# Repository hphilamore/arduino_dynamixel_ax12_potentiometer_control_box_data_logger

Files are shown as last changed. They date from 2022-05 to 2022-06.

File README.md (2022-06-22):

A robot tentacle actuated uisng 3 dynamixel ax-12 servo motors. Circuit based on an arduino uno and DFrobot Smart Arduino Digital Servo Shield for Dynamixel AX.

__________________________________________________________________________________________

Robot Tentacle Control Instructions 

1.	Turn on by connecting to mains power
2.	The motors will take approx. 10 seconds to initialise - once this setup is completed, the green LEDs on the sliders will come on. 
(If during this time the green LEDs flash 5 times, the SD card is not connected/setup correctly and logging will not take place. Fix the problem then press the reset button on the Arduino to restart.)
3.	Control the robot tentacle by moving the sliders
4.	To record the motor angles during operation, press the blue button. The light on the button will come on to indicate logging has started.
(If no light comes on, there is a problem with the SD card.) 
5.	To stop recording press the blue button again. 
It is important to stop any recordings before powering off the system to avoid corrupting the SD card and losing data!

__________________________________________________________________________________________

Bill of Materials 

- Laser cut parts (.dxf file in repo)
- 1 x Arduino Uno: https://uk.rs-online.com/web/p/arduino/7154081/
- 1 x SD card module + SD card: https://www.amazon.co.uk/arduino-sd-card-module/s?k=arduino+sd+card+module
- 1 x RTC module: hhttps://learn.sparkfun.com/tutorials/real-time-clock-module-hookup-guide/all
- 3 x Slider potentiometer with LED: https://uk.rs-online.com/web/p/potentiometers/7703135/
- 3 x Latching switch with LED : https://uk.rs-online.com/web/p/push-button-switches/8207555/
- 3 x 330 ohm resistor
- power supply (7-12V): https://www.amazon.co.uk/gp/product/B09DGCJFRC/ref=ppx_yo_dt_b_asin_title_o01_s00?ie=UTF8&psc=1
- Arduino Screw Terminal Hat : https://www.amazon.co.uk/gp/product/B097G95T7Y/ref=ppx_yo_dt_b_asin_title_o05_s00?ie=UTF8&psc=1
- DFrobot Smart Arduino Digital Servo Shield for Dynamixel AX : https://www.dfrobot.com/product-958.html
- stand-offs
- strip-board

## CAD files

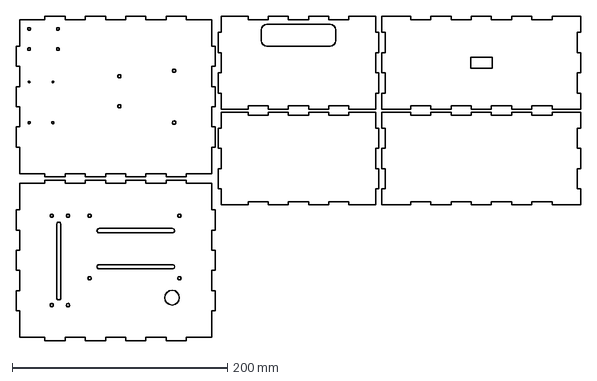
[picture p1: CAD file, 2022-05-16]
case.dxf
524.0 x 301.0 mm

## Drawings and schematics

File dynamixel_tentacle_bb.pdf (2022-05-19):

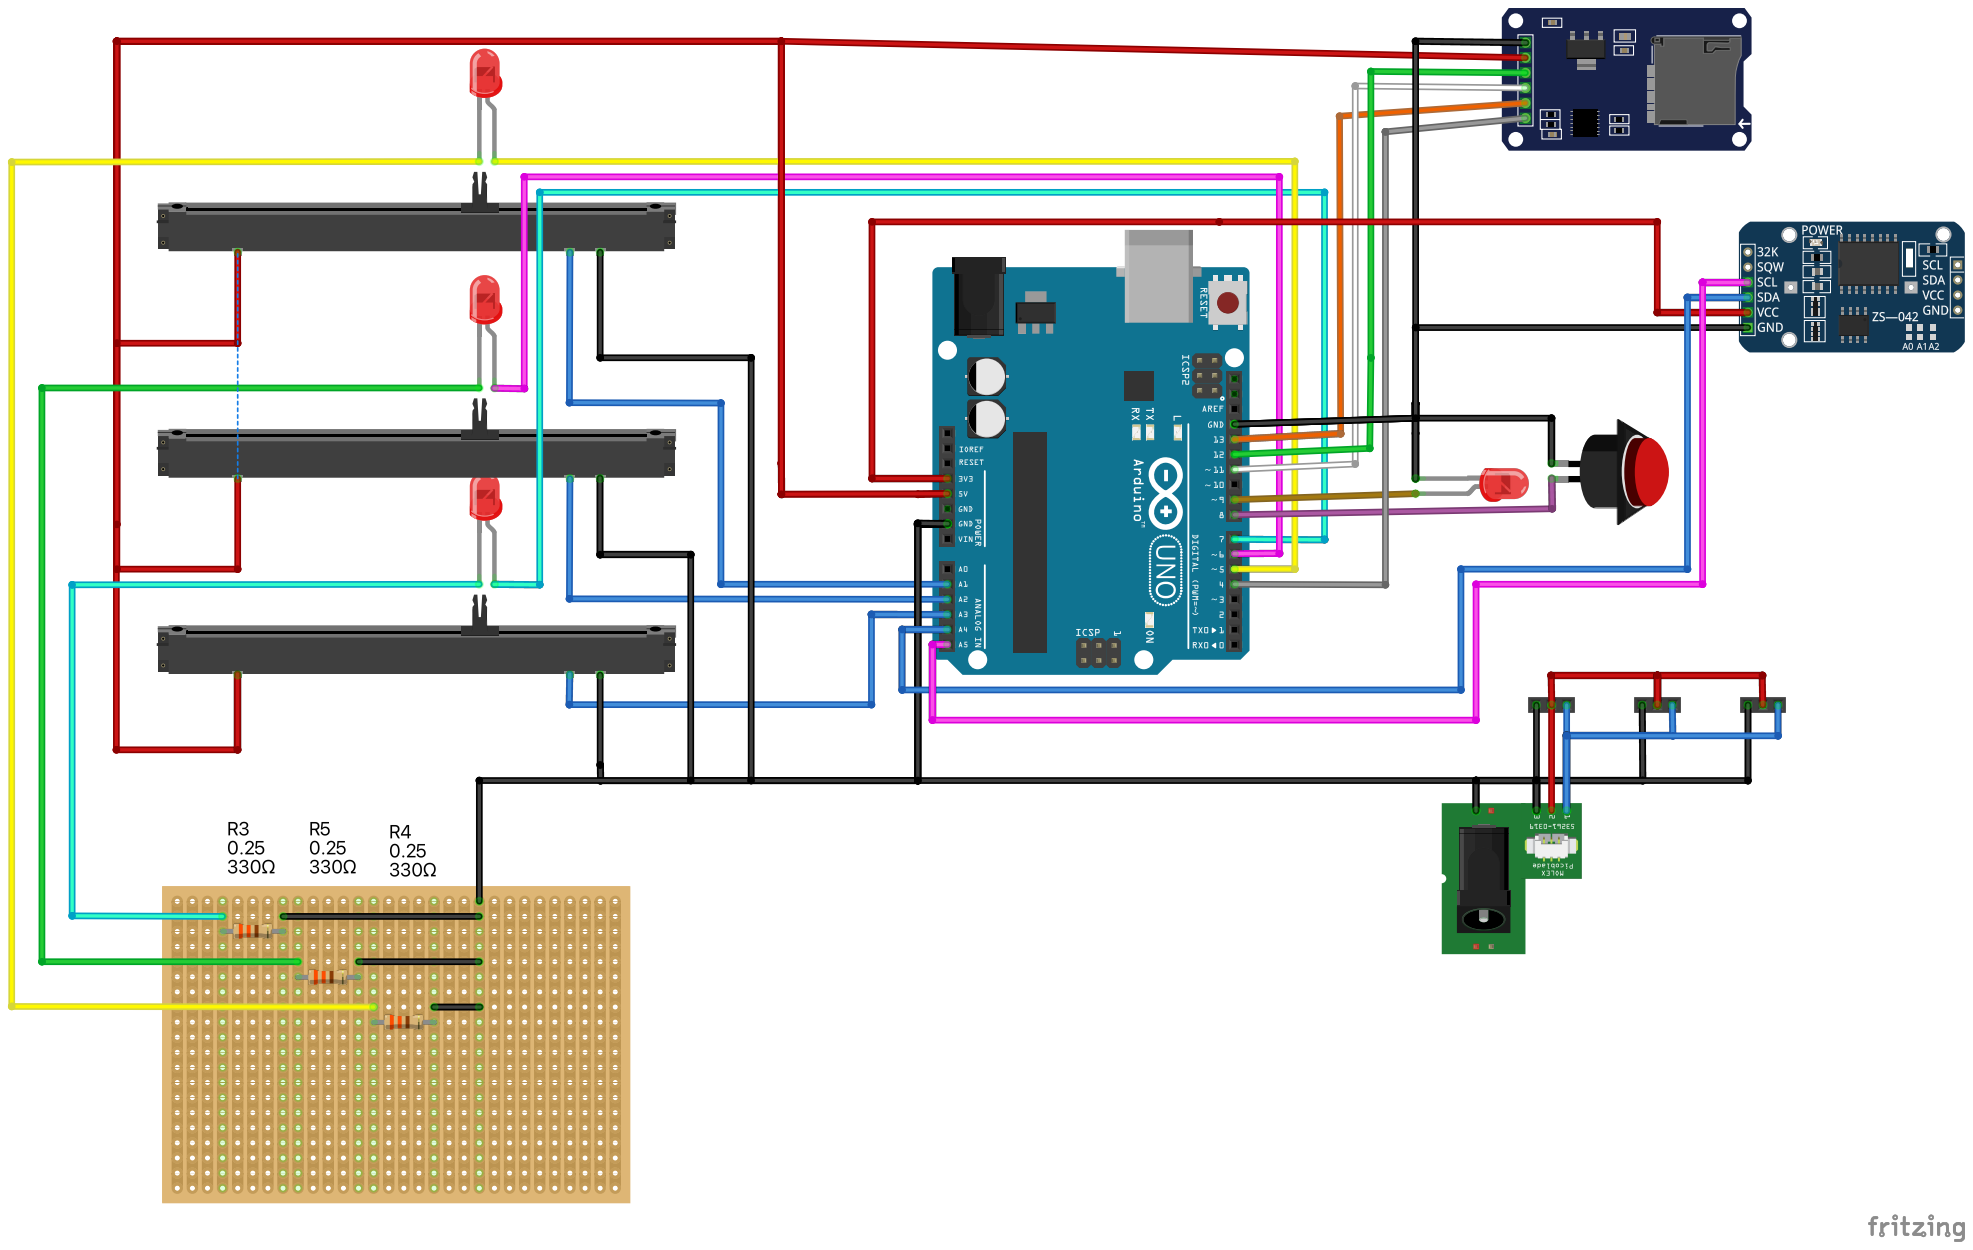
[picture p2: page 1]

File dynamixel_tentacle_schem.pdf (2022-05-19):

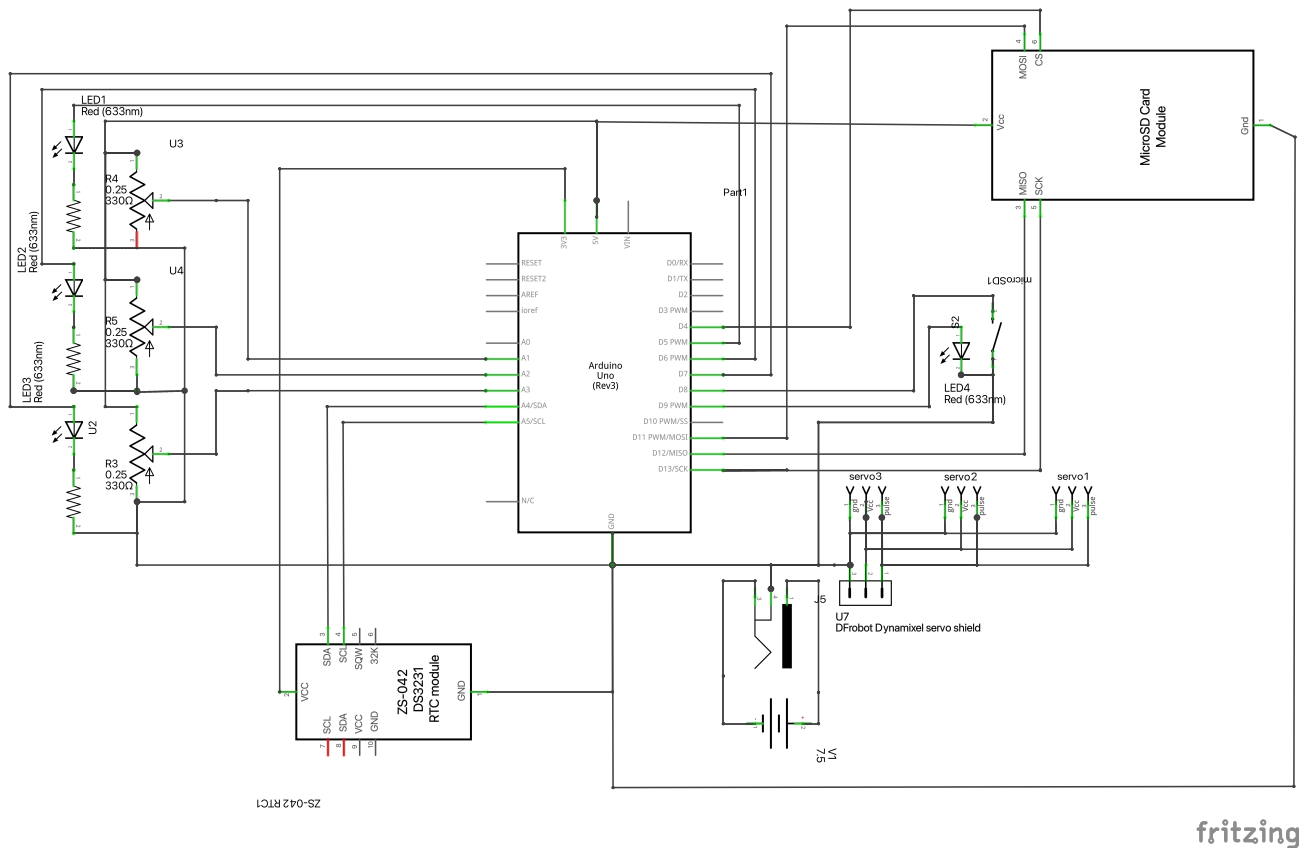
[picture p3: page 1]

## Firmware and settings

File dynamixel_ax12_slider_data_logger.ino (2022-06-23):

/*
 * 
Potentiometer sliders to control the position of 3 Dynamixel A-12 
digital servo motors Latching push button is used to control 
potentiometer value and servo position, as time series, to an SD card. 

*/

#include <SPI.h>
#include <SD.h>
File myFile;

#include <RTClib.h>
RTC_DS3231 rtc;

#include <ServoCds55.h>
ServoCds55 myservo;

// set up variables using the SD utility library functions:
Sd2Card card;
SdVolume volume;
SdFile root;

const int chipSelect = 4;          // change this to match your SD shield or module; Uno=4, Mega=53

int servoNum = 1;
char inputCommand ;                // a string to hold incoming data
boolean inputComplete = false;

const int sliders[] = {A1, A2, A3};// slider potentiometers to control motors
const int n_sliders = 3;           // number of sliders
const int LEDs[] = {5, 6, 7};      // LEDs on sliders
const int n_LEDs = 3;              // number of LEDs
const int button_LED = 8;          // LED on data record button
const int button = 9;              // data record button

int slider_vals [3];               // buffer to hold slider  values
int servo_vals [3];                // buffer to hold servo positions 

// Set max ad min values for mapping slider potentiometer to servo position 
const int pot_max = 1023;          // max potentiometer value
const int pot_min = 0;             // min potentiometer value           
const int servo_max = 300;         // servo max position (max range = [0, 300])
const int servo_min = 0;           // servo min position

bool button_status = LOW;          // default data record button position
bool SD_present = HIGH;            // default SD card status

String filename = "file_0.txt";




void setup () {
  Serial.begin (115200);
  myservo.begin ();
  pinMode(button_LED, OUTPUT);       
  pinMode(button, INPUT_PULLUP);    

  while (!Serial) {
    ; // wait for serial port to connect. Needed for native USB port only
  }
  
 
  // SETUP RTC MODULE
  Serial.print("Initializing RTC...");
  if (!rtc.begin()) {
    Serial.println(F("Couldn't find RTC"));
    delay(500);
  }

  // When time needs to be set on a new device, or after a power loss
  // Set the RTC to the date & time this sketch was compiled
  rtc.adjust(DateTime(F(__DATE__), F(__TIME__)));
  
  // SETUP SD CARD
  Serial.print("Initializing SD card...");
  if (!SD.begin(chipSelect) or !card.init(SPI_HALF_SPEED, chipSelect) or !volume.init(card)) {
    
    // Identify problem
    if (!card.init(SPI_HALF_SPEED, chipSelect)) {
      Serial.println("card not detected!");
      delay(500);
    }

    if (!volume.init(card)) {
      Serial.println("FAT 16/32 partition not detected!");
      delay(500);
    }
    
    // Flash slider LEDs 5 times to show SD card initialization failed 
    Serial.println("initialization failed!");
    SD_present = LOW;
    //while (1);
    for (int i=0; i<5; i++){
      for(int i=0; i<n_LEDs; i++){
        digitalWrite(LEDs[i], HIGH);
      }
      delay(500);
      for(int i=0; i<n_LEDs; i++){
        digitalWrite(LEDs[i], LOW);
      }
      delay(500);
    }
  }

  else{Serial.println("SD card initialization done.");}


  // SETUP SERVOS
  delay(10000);                   // allow 10 seconds for servos to initialise
  myservo.setVelocity(200);       // set velocity to 100(range:0-300) in Servo mode
  Serial.println("servos ready");
  for(int i=0; i<n_LEDs; i++){    // turn all slider LEDs on
    digitalWrite(LEDs[i], HIGH);
  } 
  
}

void loop () {
//  delay(10000);                   // allow 10 seconds for servos to initialise
//  myservo.setVelocity(200);       // set velocity to 100(range:0-300) in Servo mode
//  myservo.write(1, 150);          // set servos ID 1-3 to centre/neutral position 
//  myservo.write(2, 150);          
//  myservo.write(3, 150);          
//  Serial.println("servos ready");
//  for(int i=0; i<n_LEDs; i++){    // turn all slider LEDs on
//    digitalWrite(LEDs[i], HIGH);
//  } 


  //while(1){
    
    // Map value of each slider to corresponding servo
    for(int i=0; i<n_sliders; i++){
      Serial.print(analogRead(sliders[i]));
      slider_vals[i] = analogRead(sliders[i]);
      int servo_val = map(analogRead(sliders[i]), pot_min, pot_max, servo_min, servo_max);  
      servo_vals[i] = servo_val;
      Serial.print(" ");
      Serial.print(servo_val);
      Serial.print("    ");
      myservo.write(i+1, servo_val);
      }
    Serial.println();

    // If record button is released 
    if(digitalRead(button) == HIGH){   // button released (internal pullup)
      digitalWrite(button_LED, LOW);   // turn the record button LED off
      Serial.println("stop");
      if(button_status){               // if newly released
        Serial.println("closing file");// stop recording 
        myFile.close();
        button_status = LOW;
      }
     }
      
  
    // If button is pressed 
    else{                              
      if(SD_present){digitalWrite(button_LED, HIGH);}   // turn the record button on 
      Serial.println("record");
      if(!button_status){                               // if newly pressed
        button_status = HIGH;
        for(int i=0; i<100; i++){                       // check for exting files of format "file_x.txt"
          Serial.println("file_" + String(i) + ".txt");
          if(SD.exists("file_" + String(i) + ".txt")){
            Serial.println(" exists");
          }
          else{
            filename = "file_" + String(i) + ".txt";   // when an unused file name is found
            Serial.println("new_file_name"); 
            myFile = SD.open(filename, FILE_WRITE);    // open the file
            myFile.println();
            // write column headings
            myFile.println("Date, Time, ms_from_start, slider_1, servo_1, slider_2, servo_2, slider_3, servo_3");
            break;  
          }
          //delay(1000);
        }
       }
      
      DateTime now = rtc.now();

      myFile.print(now.year(), DEC);     // write date to SD card
      myFile.print("-");
      myFile.print(now.month(), DEC);
      myFile.print("-");
      myFile.print(now.day(), DEC);
      myFile.print(" , ");


      myFile.print(now.hour(), DEC);     // write time to SD card
      myFile.print("-");
      myFile.print(now.minute(), DEC);
      myFile.print("-");
      myFile.print(now.second(), DEC);
      myFile.print(" , ");
      
                         
      unsigned long Time = millis();     // write ms since start of recording to SD card
      myFile.print(Time);                
      myFile.print(" , ");

      
      for(int i=0; i<n_sliders; i++){
        myFile.print(slider_vals[i]);    // write slider vals to SD card
        myFile.print(" , ");
        myFile.print(servo_vals[i]);     // write servo vals to SD card
        myFile.print(" , ");
      }
      myFile.println();
     }
   //}
   //Serial.println(button_status);

//  serialEvent();
//  if (inputComplete) {
//    Serial.print("Your command is: "); Serial.println(inputCommand); Serial.println("");
//    controlServo(inputCommand);
//    // clear the command:
//    inputCommand = 0;
//    inputComplete = false;
//  }
}

void serialEvent() {
  while (Serial.available()) {
    char inChar = (char)Serial.read();
    if (inChar == '\n') {
      inputComplete = true;
      break;
    }
    inputCommand += inChar;
  }
}

void controlServo(char val) {
  switch (val) {
    case 'p':
      myservo.write(1, 300); //ID:1  Pos:300  velocity:150
      delay(3000);
      myservo.write(1, 0); //ID:1  Pos:0  velocity:150
      break;
    case 'q':
      myservo.write(2, 300); //ID:1  Pos:300  velocity:150
      delay(3000);
      myservo.write(2, 0); //ID:1  Pos:0  velocity:150
      break;
    case 'v':
      myservo.setVelocity(200);// set velocity to 100(range:0-300) in Servo mode
      break;      
    case 'r':
      myservo.Reset(servoNum);//Restore ID2 servo to factory Settings ( ID:1  Baud rate:1000000)
      break;
    case 'i':
      myservo.SetID(1,2);//ID:1   newID:2
      break;
    case 'd':  //Reset servo to ID>>servoNum. If you don't know your Servo ID, please send "d".
      Serial.print("Please wait..");
      for (int buf = 0; buf < 255; buf++) {
        myservo.SetID(buf, servoNum);
        if (buf % 50 == 0) Serial.print(".");
      }
      delay(2000);
      Serial.println("");   Serial.println("Please close the monitor and re-open it to play your servo! ");
      break;
    default:
      Serial.println("Please give me an available instruction:");
      Serial.println("  Servo mode: p_Set position; v_Set velocity.");
      Serial.println("  Motor mode: m_Rotate; v_Set velocity.");
      Serial.println("  Others: r_Reset servo to factory settings; i_Change servo ID."); Serial.println("");
  }
}

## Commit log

2022-05-03 different servo IDs to control seperate servos independently. Servo IDs pre-assigned
2022-05-03 sliders to control servo position
2022-05-03 independent control of 2 servos using potentiometer sliders as input
2022-05-06 3 sliders control 3 servos with IDs 1-3 independently
2022-05-06 logging 3 slider values and 3 servo positions to SD card
2022-05-13 milestone wrking version: logging to SD card + controlled by buttons
2022-05-13 delays removed. millis timestamp added
2022-05-15 remove lines to centre servos when code starts up. servos will start up at initial position set by sliders
2022-05-16 RTC added, CAD files for laser cutting and README added
    [case.dxf]
2022-05-19 schematics added
2022-05-23 BOM updated
2022-06-23 file name change
    [dynamixel_tentacle.fzz]
